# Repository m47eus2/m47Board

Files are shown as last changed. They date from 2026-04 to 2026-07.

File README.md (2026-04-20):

# m47Board

## Custom PCB designed for STM32 Dev Board
- STM32C031C6T6 MCU
- HSE and LSE external oscillators
- SWD programming interface
- Goldpin headers for all GPIO pins
- User button and user LED
- TLV1117LV33 5V to 3.3V 1A LDO
- RST button

## PCB render

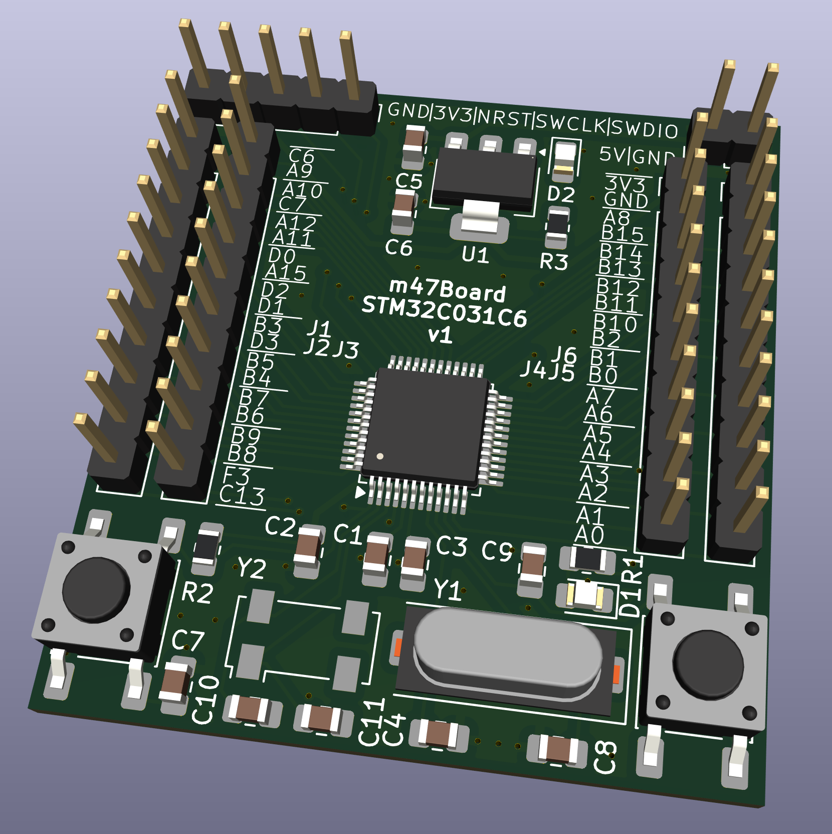
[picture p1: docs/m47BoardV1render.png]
PCBrender


## Schematic

Schematic

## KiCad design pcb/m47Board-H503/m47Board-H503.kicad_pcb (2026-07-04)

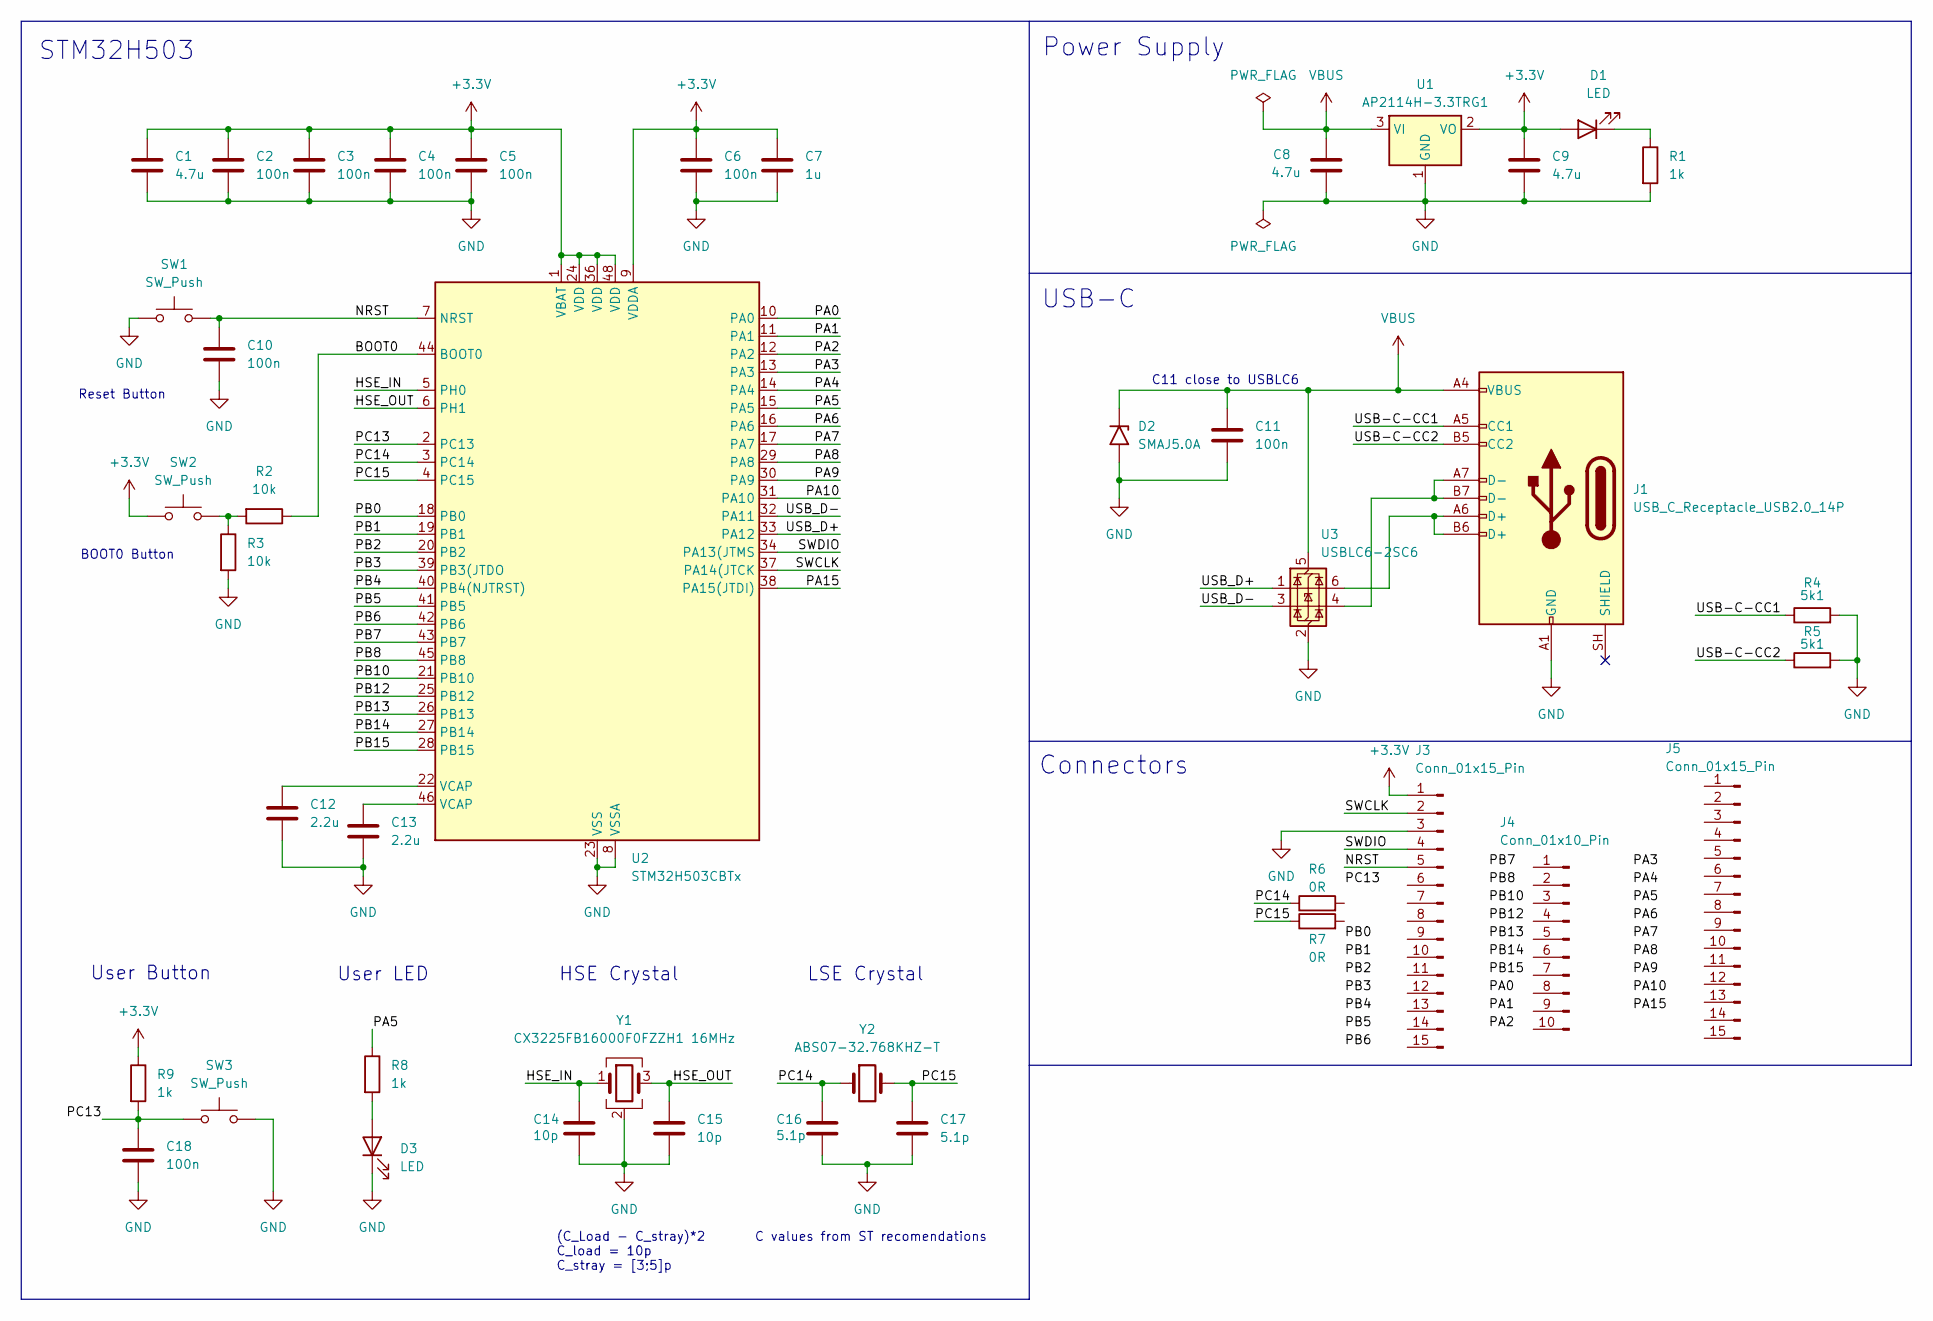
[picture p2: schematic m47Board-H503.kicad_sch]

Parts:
C1, C8, C9: 4.7u; C_0805_2012Metric_Pad1.18x1.45mm_HandSolder
C2, C3, C4, C5, C6, C10, C11, C18: 100n; C_0402_1005Metric_Pad0.74x0.62mm_HandSolder
C7: 1u; C_0805_2012Metric_Pad1.18x1.45mm_HandSolder
C12, C13: 2.2u; C_0805_2012Metric_Pad1.18x1.45mm_HandSolder
C14, C15: 10p; C_0402_1005Metric_Pad0.74x0.62mm_HandSolder
C16, C17: 5.1p; C_0402_1005Metric_Pad0.74x0.62mm_HandSolder
D1, D3: LED; LED_0805_2012Metric_Pad1.15x1.40mm_HandSolder
D2: SMAJ5.0A; D_SMA
J1: USB_C_Receptacle_USB2.0_14P; USB_C_Receptacle_GCT_USB4105-xx-A_16P_TopMnt_Horizontal
J3, J5: Conn_01x15_Pin; PinHeader_1x15_P2.54mm_Vertical
J4: Conn_01x10_Pin; PinHeader_1x10_P2.54mm_Vertical
R1, R8, R9: 1k; R_0402_1005Metric_Pad0.72x0.64mm_HandSolder
R2, R3: 10k; R_0402_1005Metric_Pad0.72x0.64mm_HandSolder
R4, R5: 5k1; R_0402_1005Metric_Pad0.72x0.64mm_HandSolder
R6, R7: 0R; R_0402_1005Metric_Pad0.72x0.64mm_HandSolder
SW1, SW2, SW3: SW_Push; SW_Push_1P1T_NO_E-Switch_TL3301NxxxxxG
U1: AP2114H-3.3TRG1; SOT-223-3_TabPin2
U2: STM32H503CBTx; LQFP-48_7x7mm_P0.5mm
U3: USBLC6-2SC6; SOT-23-6
Y1: CX3225FB16000F0FZZH1 16MHz; Crystal_SMD_3225-4Pin_3.2x2.5mm
Y2: ABS07-32.768KHZ-T; Crystal_SMD_3215-2Pin_3.2x1.5mm

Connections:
+3.3V: C1.1, C2.1, C3.1, C4.1, C5.1, C6.1, C7.1, C9.1, D1.2 (A), J3.1, R9.1, SW2.1, U1.2 (VO), U2.1 (VBAT), U2.9 (VDDA), U2.24 (VDD), U2.36 (VDD), U2.48 (VDD)
/BOOT0: R2.1, U2.44 (BOOT0)
/HSE_IN: C14.1, U2.5 (PH0), Y1.1
/HSE_OUT: C15.1, U2.6 (PH1), Y1.3
/NRST: C10.1, J3.5, SW1.2, U2.7 (NRST)
/PA0: U2.10 (PA0)
/PA1: U2.11 (PA1)
/PA2: U2.12 (PA2)
/PA3: U2.13 (PA3)
/PA4: U2.14 (PA4)
/PA5: R8.1, U2.15 (PA5)
/PA6: U2.16 (PA6)
/PA7: U2.17 (PA7)
/PA8: U2.29 (PA8)
/PA9: U2.30 (PA9)
/PA10: U2.31 (PA10)
/PA15: U2.38 (PA15(JTDI))
/PB0: U2.18 (PB0)
/PB1: U2.19 (PB1)
/PB2: U2.20 (PB2)
/PB3: U2.39 (PB3(JTDO)
/PB4: U2.40 (PB4(NJTRST))
/PB5: U2.41 (PB5)
/PB6: U2.42 (PB6)
/PB7: U2.43 (PB7)
/PB8: U2.45 (PB8)
/PB10: U2.21 (PB10)
/PB12: U2.25 (PB12)
/PB13: U2.26 (PB13)
/PB14: U2.27 (PB14)
/PB15: U2.28 (PB15)
/PC13: C18.1, R9.2, SW3.1, U2.2 (PC13)
/PC14: C16.1, R6.1, U2.3 (PC14), Y2.1
/PC15: C17.1, R7.1, U2.4 (PC15), Y2.2
/SWCLK: J3.2, U2.37 (PA14(JTCK)
/SWDIO: J3.4, U2.34 (PA13(JTMS)
/USB-C-CC1: J1.A5 (CC1), R4.1
/USB-C-CC2: J1.B5 (CC2), R5.1
/USB_D+: U2.33 (PA12), U3.1 (I/O1)
/USB_D-: U2.32 (PA11), U3.3 (I/O2)
GND: C1.2, C2.2, C3.2, C4.2, C5.2, C6.2, C7.2, C8.2, C9.2, C10.2, C11.2, C12.2, C13.2, C14.2, C15.2, C16.2, C17.2, C18.2, D2.2 (A2), D3.1 (K), J1.A1 (GND), J1.A12 (GND), J1.B1 (GND), J1.B12 (GND), J3.3, R1.2, R3.2, R4.2, R5.2, SW1.1, SW3.2, U1.1 (GND), U2.8 (VSSA), U2.23 (VSS), U2.35 (VSS), U2.47 (VSS), U3.2 (GND), Y1.2 (G), Y1.4 (G)
unnamed: C12.1, U2.22 (VCAP)
unnamed: C13.1, U2.46 (VCAP)
unnamed: D1.1 (K), R1.1
unnamed: D3.2 (A), R8.2
unnamed: J1.A6 (D+), J1.B6 (D+), U3.6 (I/O1)
unnamed: J1.A7 (D-), J1.B7 (D-), U3.4 (I/O2)
unnamed: R2.2, R3.1, SW2.2
VBUS: C8.1, C11.1, D2.1 (A1), J1.A4 (VBUS), J1.A9 (VBUS), J1.B4 (VBUS), J1.B9 (VBUS), U1.3 (VI), U3.5 (VBUS)

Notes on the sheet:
USB-C
LSE Crystal
Reset Button
User Button
C values from ST recomendations
BOOT0 Button
Power Supply
C11 close to USBLC6
(C_Load - C_stray)*2 C_load = 10p C_stray = [3;5]p
STM32H503
User LED
Connectors
HSE Crystal

Board: 2 copper layers, 42 parts (0 on the bottom side), 24 nets, no tracks yet.

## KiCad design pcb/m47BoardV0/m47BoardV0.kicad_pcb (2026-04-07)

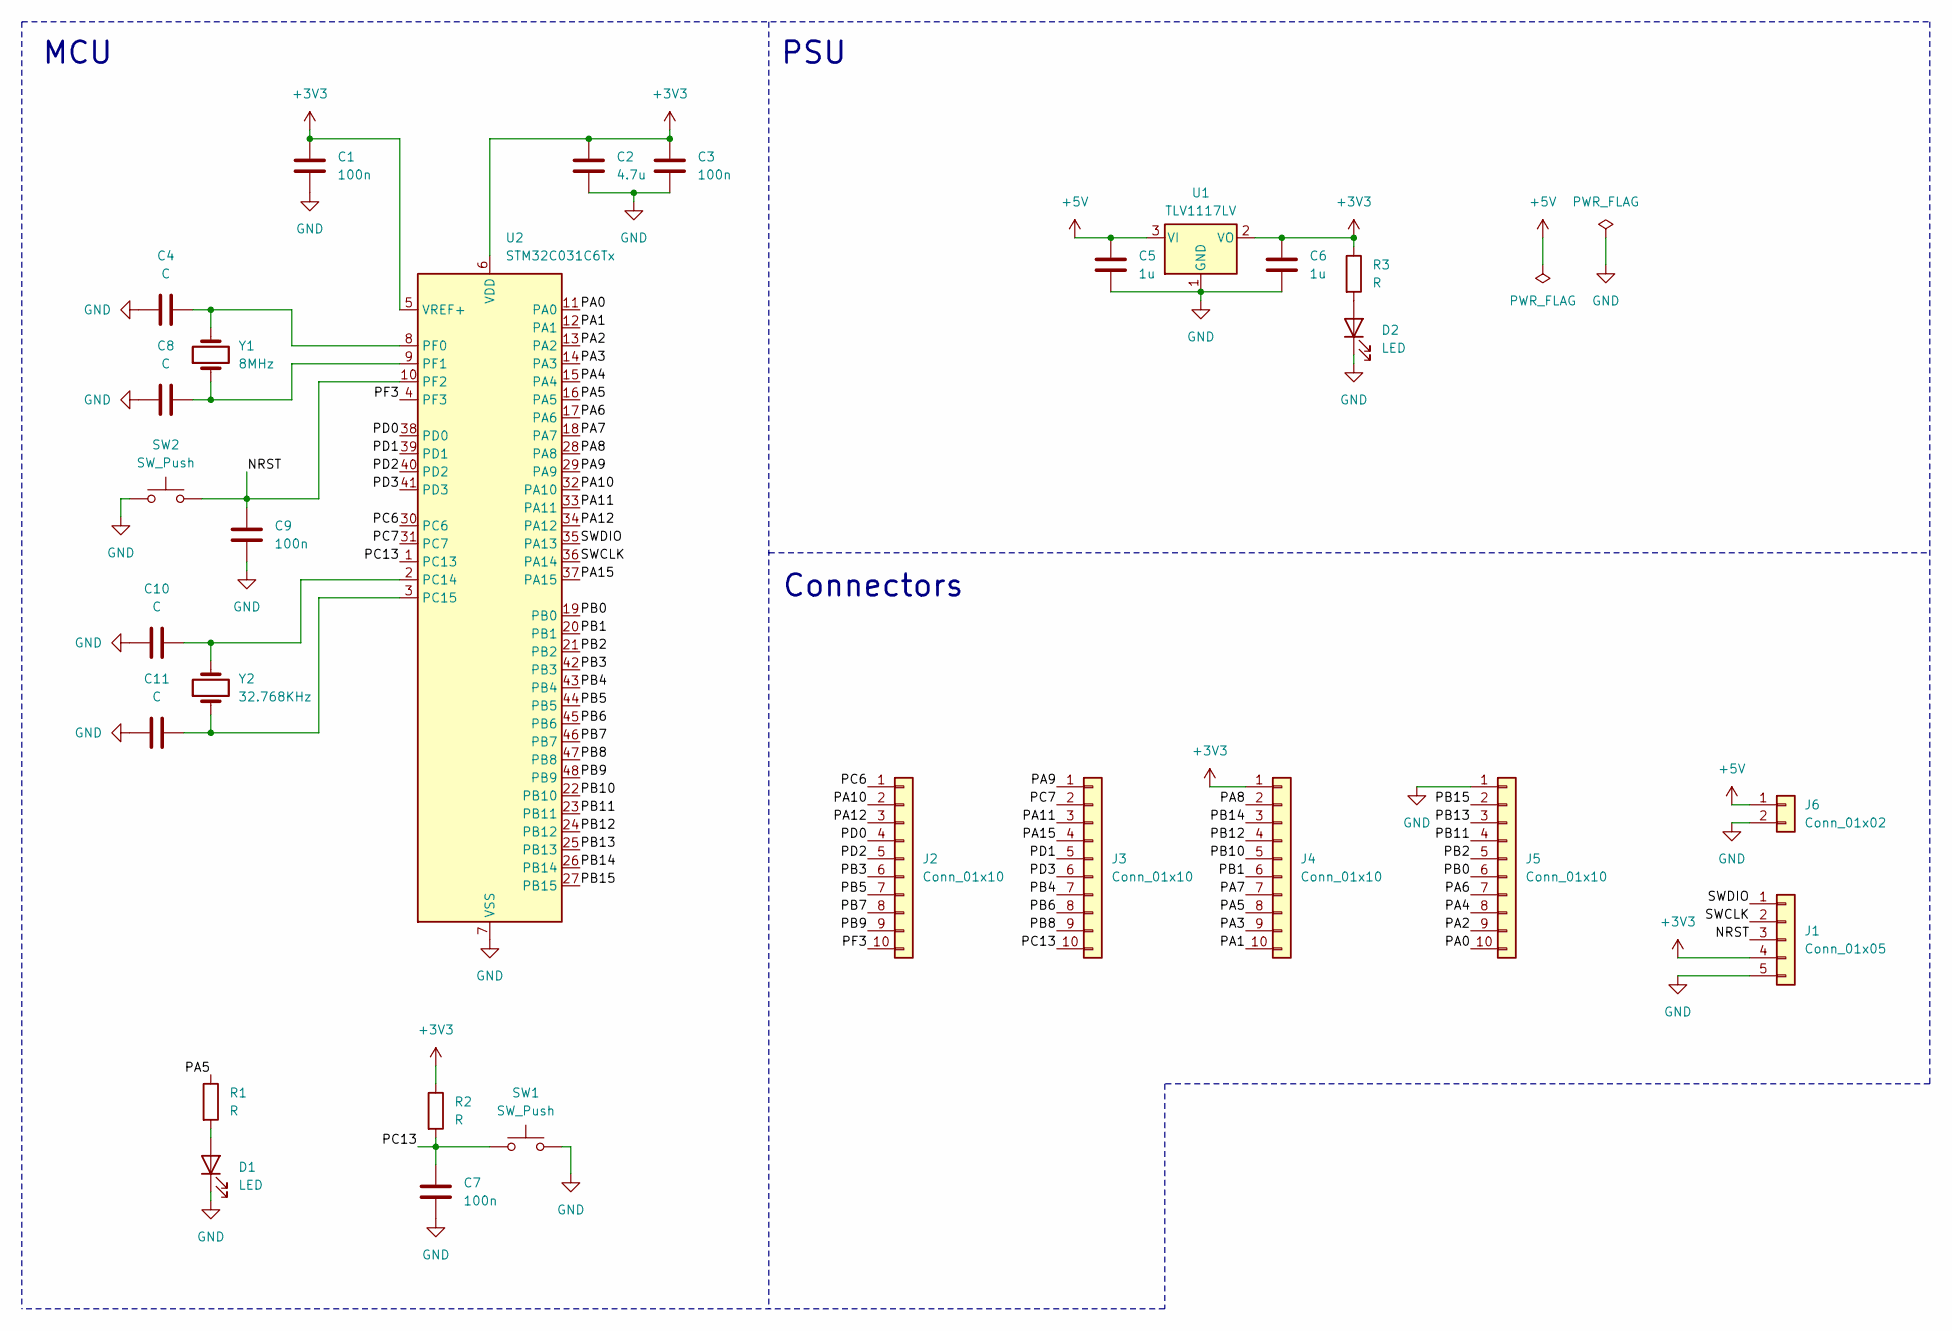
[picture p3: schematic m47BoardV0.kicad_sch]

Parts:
C1, C3, C7, C9: 100n; C_0805_2012Metric_Pad1.18x1.45mm_HandSolder
C2: 4.7u; C_0805_2012Metric_Pad1.18x1.45mm_HandSolder
C4, C8, C10, C11: C; C_0805_2012Metric_Pad1.18x1.45mm_HandSolder
C5, C6: 1u; C_0805_2012Metric_Pad1.18x1.45mm_HandSolder
D1, D2: LED; LED_0805_2012Metric_Pad1.15x1.40mm_HandSolder
J1: Conn_01x05; PinHeader_1x05_P2.54mm_Vertical
J2, J3, J4, J5: Conn_01x10; PinHeader_1x10_P2.54mm_Vertical
J6: Conn_01x02; PinHeader_1x02_P2.54mm_Vertical
R1, R2, R3: R; R_0805_2012Metric_Pad1.20x1.40mm_HandSolder
SW1, SW2: SW_Push; SW_Push_1P1T_NO_E-Switch_TL3301NxxxxxG
U1: TLV1117LV; SOT-223-LTV1117LV
U2: STM32C031C6Tx; LQFP-48_7x7mm_P0.5mm
Y1: 8MHz; Crystal_SMD_HC49-SD
Y2: 32.768KHz; Crystal_SMD_Abracon_ABS25-4Pin_8.0x3.8mm

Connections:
+3V3: C1.1, C2.1, C3.1, C6.1, J1.4, J4.1, R2.1, R3.1, U1.2 (VO), U2.5 (VREF+), U2.6 (VDD)
+5V: C5.1, J6.1, U1.3 (VI)
/NRST: C9.1, J1.3, SW2.2, U2.10 (PF2)
/PA0: J5.10, U2.11 (PA0)
/PA1: J4.10, U2.12 (PA1)
/PA2: J5.9, U2.13 (PA2)
/PA3: J4.9, U2.14 (PA3)
/PA4: J5.8, U2.15 (PA4)
/PA5: J4.8, R1.1, U2.16 (PA5)
/PA6: J5.7, U2.17 (PA6)
/PA7: J4.7, U2.18 (PA7)
/PA8: J4.2, U2.28 (PA8)
/PA9: J3.1, U2.29 (PA9)
/PA10: J2.2, U2.32 (PA10)
/PA11: J3.3, U2.33 (PA11)
/PA12: J2.3, U2.34 (PA12)
/PA15: J3.4, U2.37 (PA15)
/PB0: J5.6, U2.19 (PB0)
/PB1: J4.6, U2.20 (PB1)
/PB2: J5.5, U2.21 (PB2)
/PB3: J2.6, U2.42 (PB3)
/PB4: J3.7, U2.43 (PB4)
/PB5: J2.7, U2.44 (PB5)
/PB6: J3.8, U2.45 (PB6)
/PB7: J2.8, U2.46 (PB7)
/PB8: J3.9, U2.47 (PB8)
/PB9: J2.9, U2.48 (PB9)
/PB10: J4.5, U2.22 (PB10)
/PB11: J5.4, U2.23 (PB11)
/PB12: J4.4, U2.24 (PB12)
/PB13: J5.3, U2.25 (PB13)
/PB14: J4.3, U2.26 (PB14)
/PB15: J5.2, U2.27 (PB15)
/PC6: J2.1, U2.30 (PC6)
/PC7: J3.2, U2.31 (PC7)
/PC13: C7.1, J3.10, R2.2, SW1.1, U2.1 (PC13)
/PD0: J2.4, U2.38 (PD0)
/PD1: J3.5, U2.39 (PD1)
/PD2: J2.5, U2.40 (PD2)
/PD3: J3.6, U2.41 (PD3)
/PF3: J2.10, U2.4 (PF3)
/SWCLK: J1.2, U2.36 (PA14)
/SWDIO: J1.1, U2.35 (PA13)
GND: C1.2, C2.2, C3.2, C4.1, C5.2, C6.2, C7.2, C8.1, C9.2, C10.1, C11.1, D1.1 (K), D2.1 (K), J1.5, J5.1, J6.2, SW1.2, SW2.1, U1.1 (GND), U2.7 (VSS)
unnamed: D1.2 (A), R1.2
unnamed: D2.2 (A), R3.2
unnamed: C10.2, U2.2 (PC14), Y2.2
unnamed: C11.2, U2.3 (PC15), Y2.1
unnamed: C4.2, U2.8 (PF0), Y1.2
unnamed: C8.2, U2.9 (PF1), Y1.1

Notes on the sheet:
MCU
Connectors
PSU

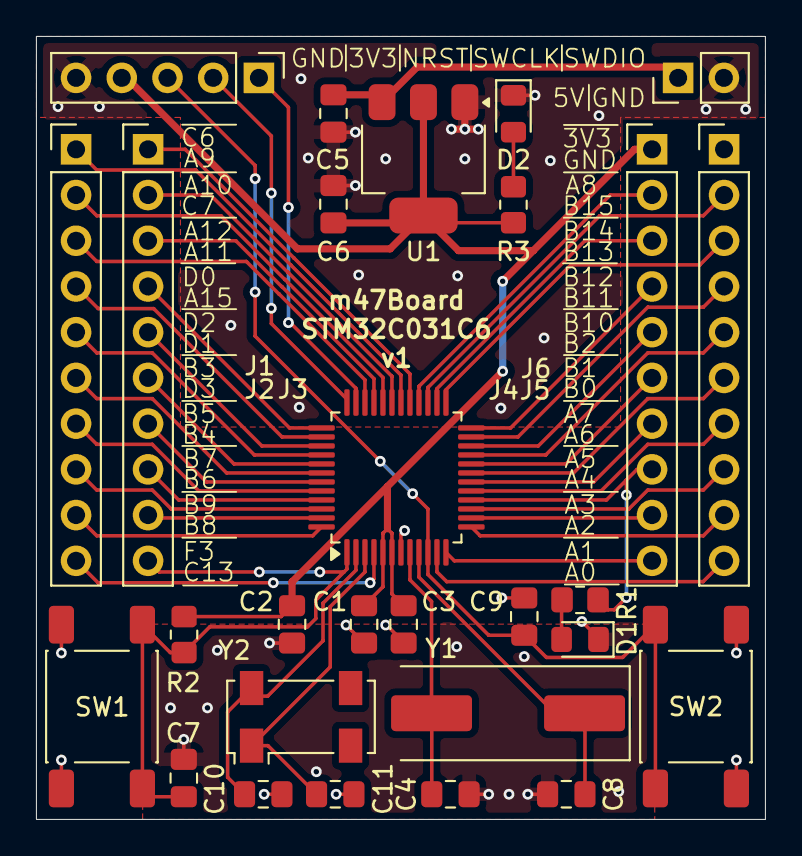
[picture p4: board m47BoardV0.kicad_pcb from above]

Board: 2 copper layers, 40.5 x 43.5 mm, 28 parts (0 on the bottom side), 50 nets.

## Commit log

2026-04-07 Adding KiCad project files and docs dir
    [m47BoardV0-B_Cu.gbr, m47BoardV0-B_Mask.gbr, m47BoardV0-B_Silkscreen.gbr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]
2026-04-28 Change project name
    [m47Board-C0-B_Cu.gbr, m47Board-C0-B_Mask.gbr, m47Board-C0-B_Silkscreen.gbr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]
2026-04-28 Add R values
    [m47Board-C0.kicad_sch]
2026-04-28 Remove gerber files from m47Board-C0
    [m47Board-C0-B_Cu.gbr, m47Board-C0-B_Mask.gbr, m47Board-C0-B_Silkscreen.gbr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]
2026-06-27 Returning to V0
    [m47Board-C0.kicad_pcb, m47Board-C0.kicad_sch]
2026-06-28 Part of schematic and pinout for m47Board-H503
    [m47Board-H503.kicad_pcb, m47Board-H503.kicad_sch]
2026-06-29 Update m47Board-H503 schematic
    [m47Board-H503.kicad_sch]
2026-07-01 Add USB-C ESD protection to m47Board-H503 schematic
    [m47Board-H503.kicad_sch]
2026-07-01 Add footprints to m47Board-H503 schematic
    [m47Board-H503.kicad_sch]
2026-07-01 Start making m47Board-H503 PCB layout
    [m47Board-H503.kicad_pcb, m47Board-H503.kicad_sch]
2026-07-03 m47Board-H503 PCB layout update
    [m47Board-H503.kicad_pcb, m47Board-H503.kicad_sch]
